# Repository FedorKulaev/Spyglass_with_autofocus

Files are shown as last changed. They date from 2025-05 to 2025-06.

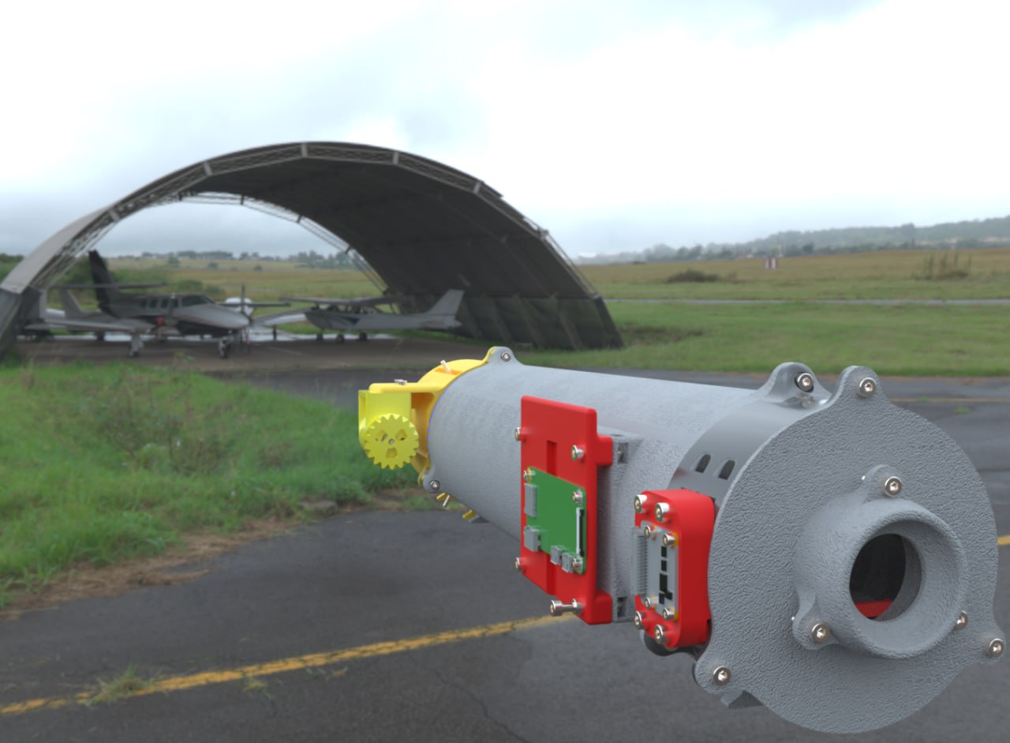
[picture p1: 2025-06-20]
Photo/photo_2025-06-21 00.15.42.jpeg

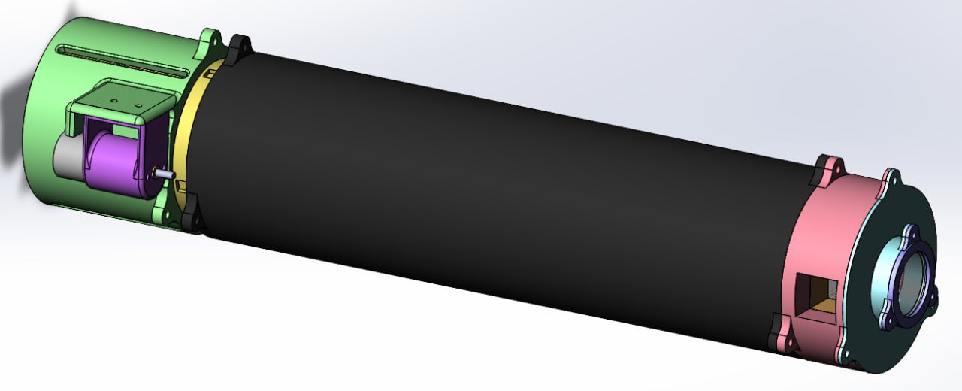
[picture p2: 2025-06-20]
Photo/photo_2025-06-21 00.15.21.jpeg

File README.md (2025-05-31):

# Краткое описание
Устройство представляет собой крупногабаритную подзорную трубу, которая обладает возможностью фокусироваться на объекты, находящиеся в диапазоне расстояний 3-10000 метров. Увеличение нашей трубы составляет 5.33, при этом изображение получается перевёрнутым. Для фокусировки устройству требуется порядка пары секунд, в течение которых подзорную трубу необходимо статично удерживать для корректной работы автофокуса.

# Команда
Кулаев Фёдор, группа Б04-303 

Ветров Алексей, группа Б04-303

# Цель проекта
Все сталкивались с проблемой, что при использовании бинокля при перенаведении его на более или менее удалённый предмет приходится двигать колёсико регулировки. Мы поставили перед собой задачу собрать устройство, которое сможет перефокусироваться автоматически. 

# Подробное описание устройства
Оптическая схема состоит из схемы Кеплера, где объектив - линза на 3 дптр, окуляр - линза на 16 дптр(Теоретическое увеличение такой схемы 5.33). В конце схемы мы добавили делитель луча. Одна половина луча попадает на камеру, с помощью которой мы понимаем, в фокусе находятся объекты или нет. Моторчиком двигаем одну линзу относительно другой до того момента, пока изображение не окажется сфокусированным. Моторчиком и состоянием фокусировки управляет микрокомпьютер. Питание за счёт powerbank.

# Компоненты
Объектив - линза для очков на 3 дптр (https://market.yandex.ru/product--linza-dlia-ochkov-sfericheskaia-1sht-ice-maker-d-65-index-1-70/1884922652?sku=102071359570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)

Окуляр - линза для очков на 16 дптр (https://market.yandex.ru/product--linza-dlia-ochkov-sfericheskaia-1sht-ice-maker-d-60-index-1-70/1884926108?sku=102071359528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)

Мотор DC205 RPM 

Драйвер к мотору TB6612FNG

Камера Pi-camera module 3

Микрокомпьютер Raspberry Pi 4 model B (изначально планировалась Raspberry Pi Zero v1.3)

PD-триггер для получения нужного напряжения с powerbank (https://www.ozon.ru/product/trigger-modul-fastcharge-9v-12v-15v-20v-1156203022/?reviewsVariantMode=2)

powerbank

# Трудности 
Наше устройство получилось довольно большим ввиду того, что мы не имеем возможности обрезать под нужный диаметр линзы, и поэтому в процессе разработки было принято решение вместо бинокля сделать подзорную трубу.

Мы хотели всё запитать с помощью одного powerbank, поэтому нам пришлось дополнительно приобрести PD-триггер для получения нужного напряжения на моторах

# Существующие аналоги
<([https://www.amazon.com/s?k=autofocus+binoculars)](https://www.amazon.com/Bushnell-Waterproof-Spectator-Binocular-10x50mm/dp/B07353SGQG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)>

<<https://binokl.shop/product/free-focus-bpsh-8x40>>

# Фото


# Видео

https://github.com/user-attachments/assets/4ccdcfca-6943-4ccf-b469-e8c1348ee5a3

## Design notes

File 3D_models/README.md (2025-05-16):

# Здесь представлены финальные версии 3D моделей всех распечатанных нами деталей
### Файлы .stl - оправы для линз, которые использовались в процессе тестирования оптической схемы
### Файл ПД-01 - сборка 3D моделей всех компонентов подзорной трубы

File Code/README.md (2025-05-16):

Тут лежат все версии программного кода, использованного нами в процессе создания и тестирования продукта

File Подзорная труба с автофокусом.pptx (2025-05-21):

## Подзорная труба с автофокусом

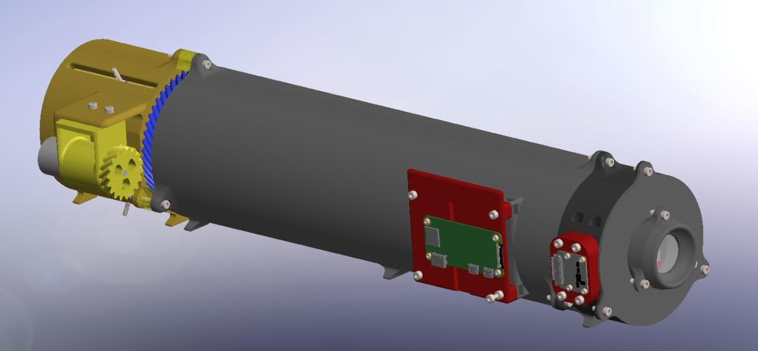
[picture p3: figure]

Команда:
Кулаев Фёдор Б04-303
Ветров Алексей Б04- 303

## Этапы создания

1. Тестирование оптической схемы
2. Проектирование компонентов
3. Печать и сборка
4. Работа с Raspberry PI
5. Подключение всех компонентов и отладка

## Тестирование оптической схемы

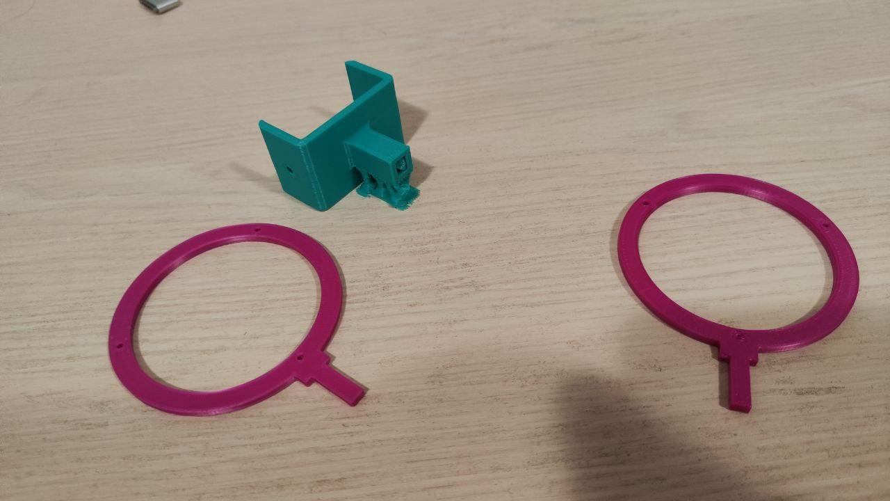
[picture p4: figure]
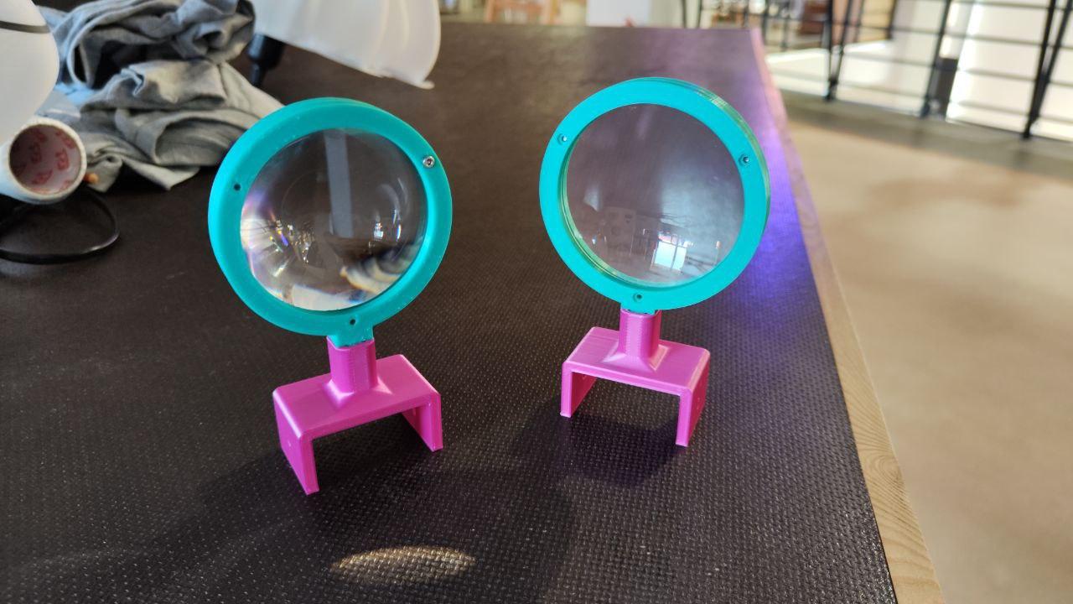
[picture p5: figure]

## Тестирование оптической схемы

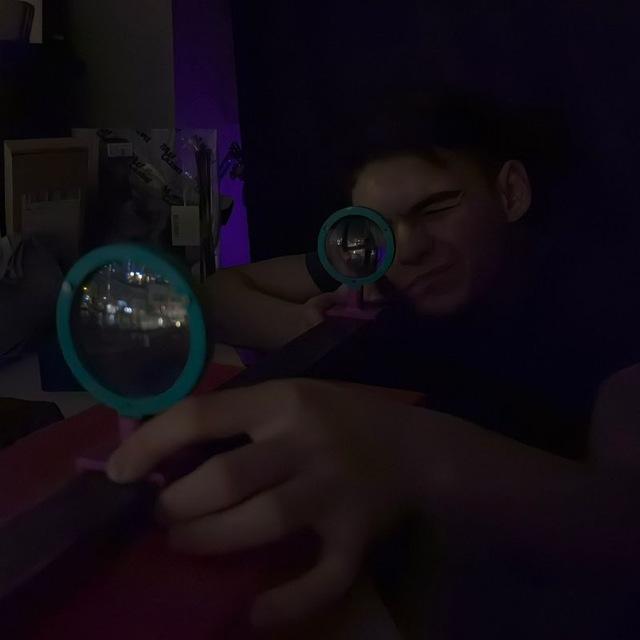
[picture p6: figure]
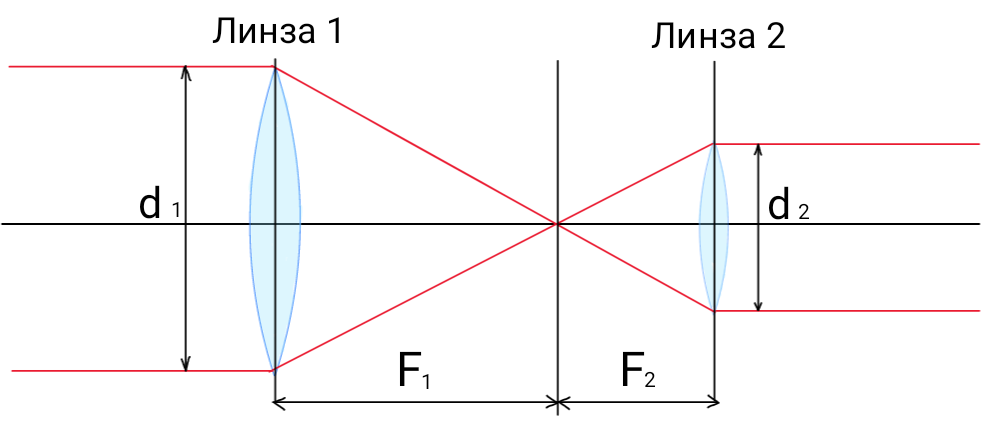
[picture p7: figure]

## 2. Проектирование компонентов

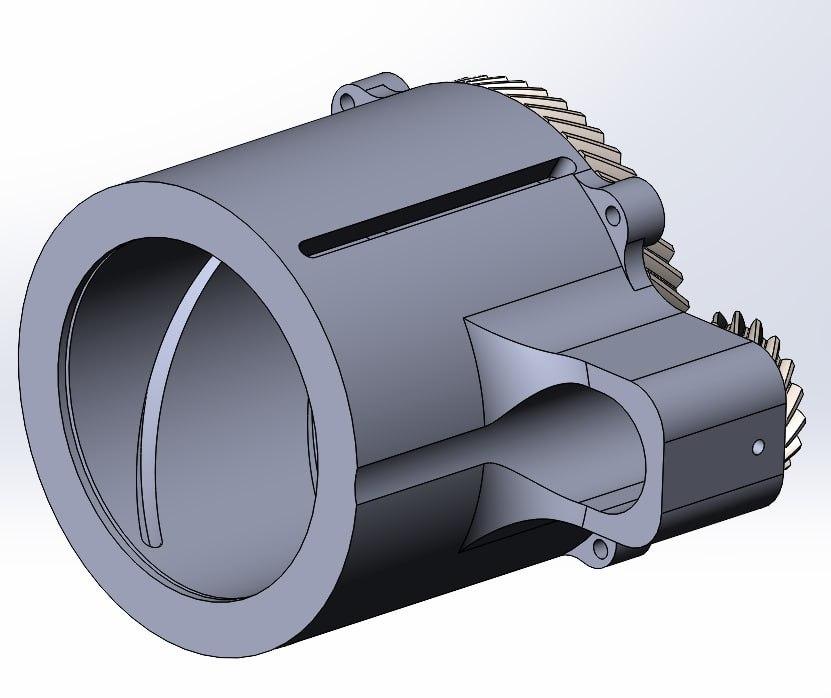
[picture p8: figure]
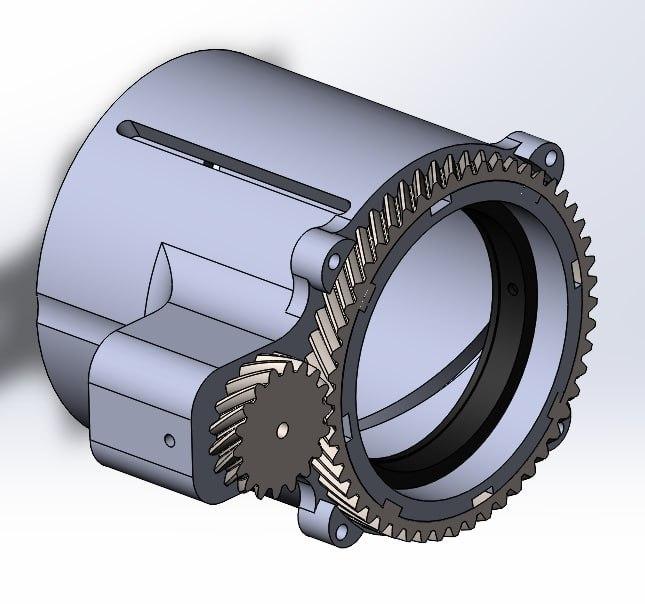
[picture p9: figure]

## 2. Проектирование компонентов

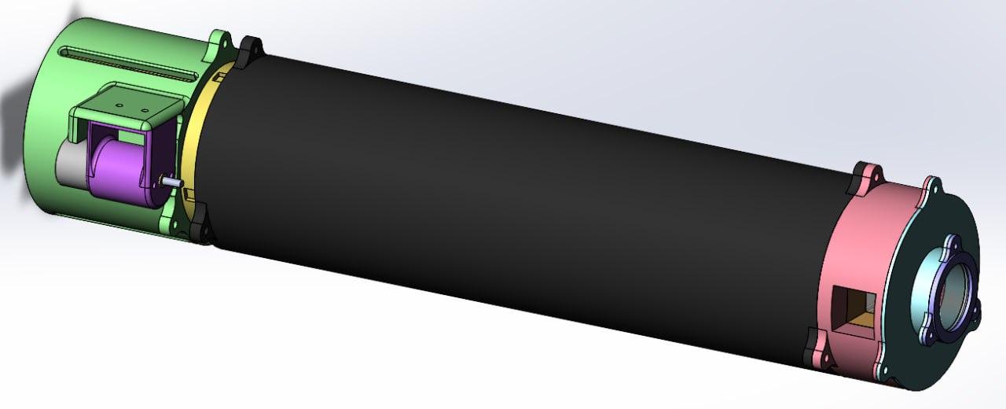
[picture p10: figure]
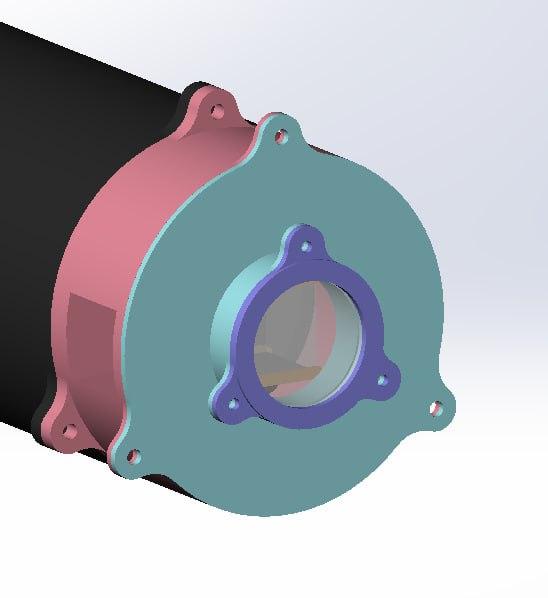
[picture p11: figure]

## 2. Проектирование компонентов

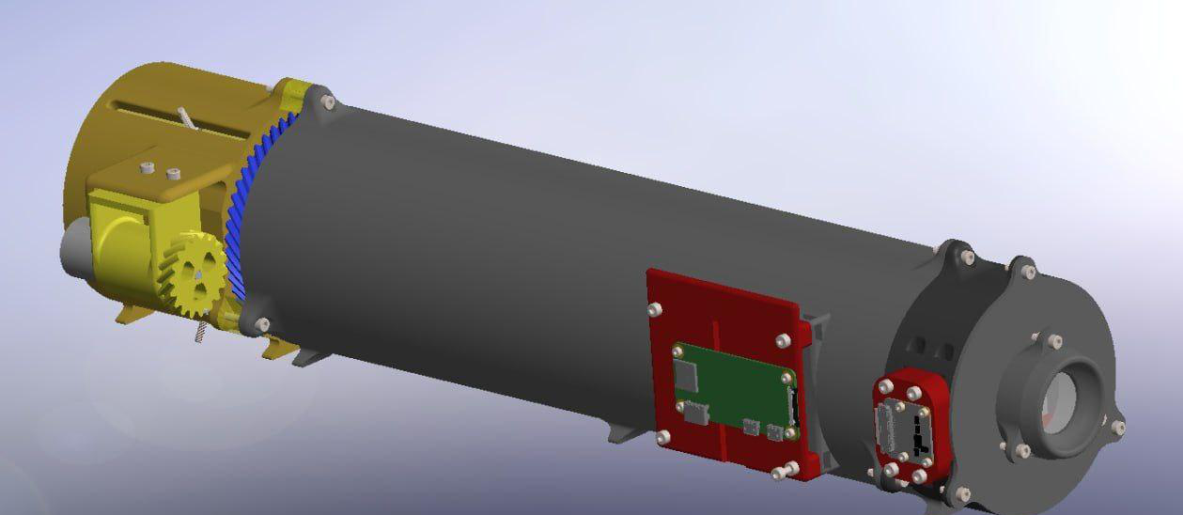
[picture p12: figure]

## 2. Проектирование компонентов

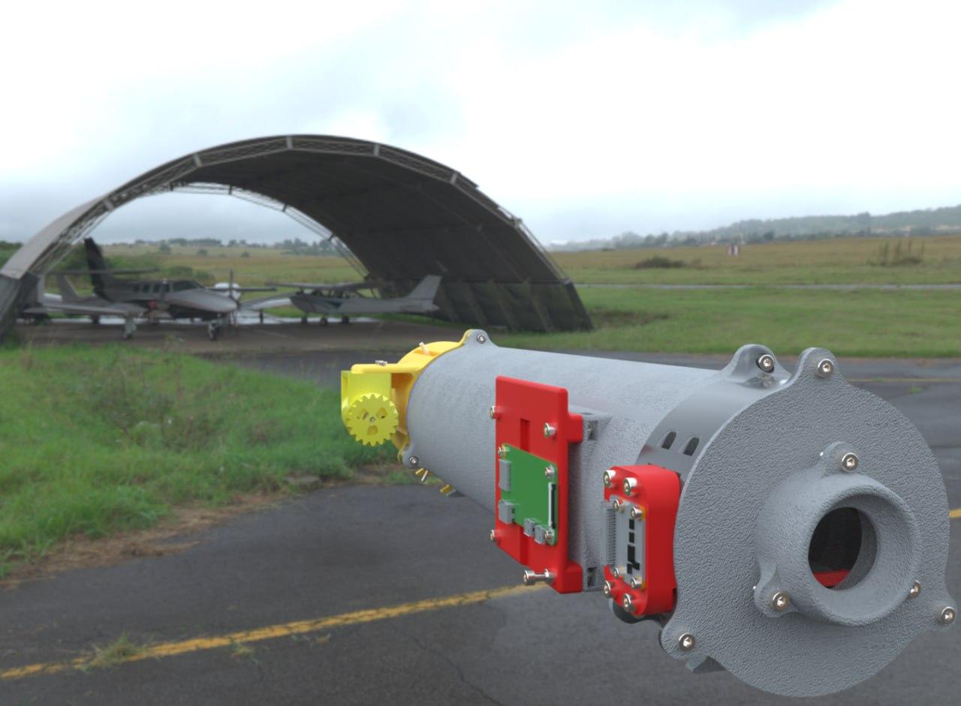
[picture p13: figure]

## 3. Печать и сборка

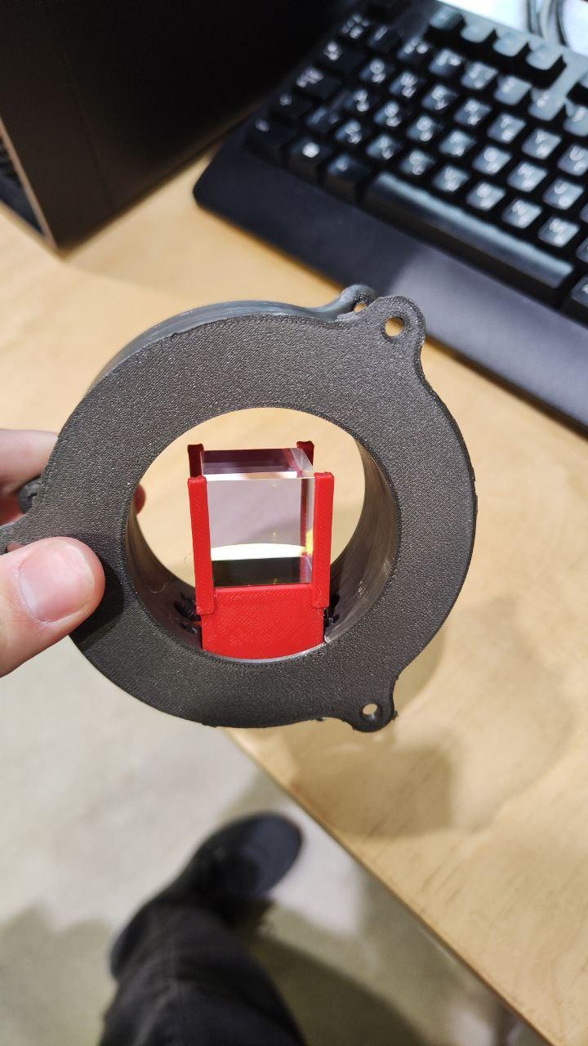
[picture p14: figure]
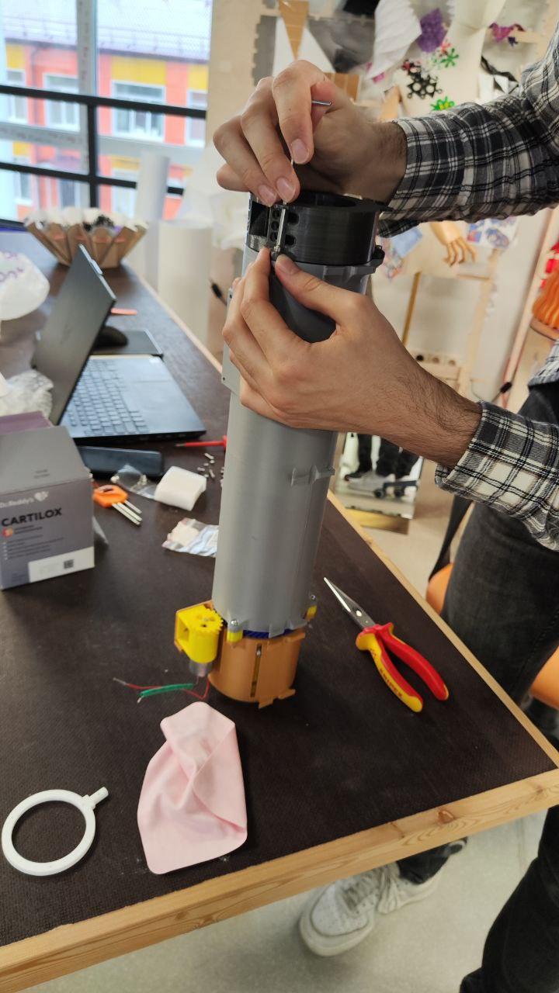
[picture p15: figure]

## 4. Работа с Raspberry Pi

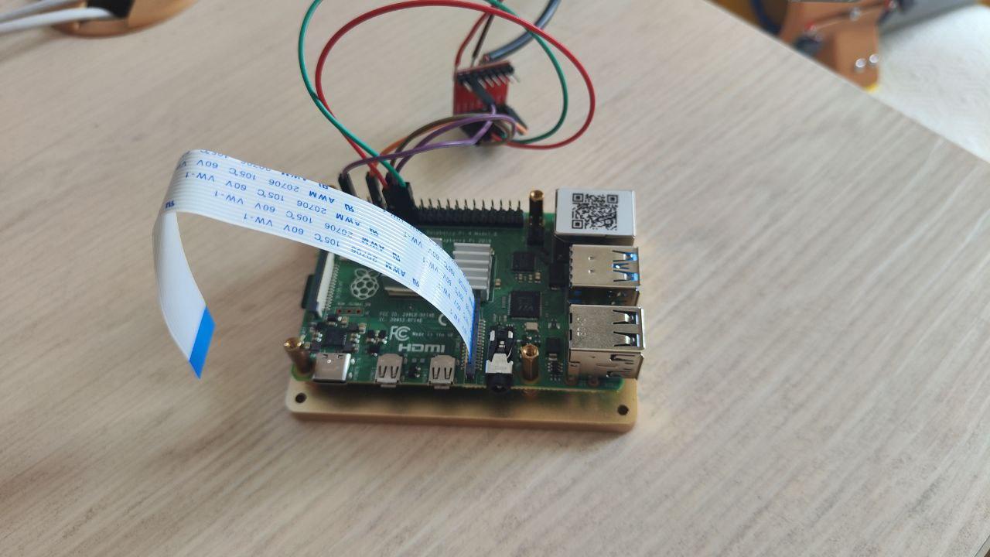
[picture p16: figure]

## 5. Подключение всех компонентов

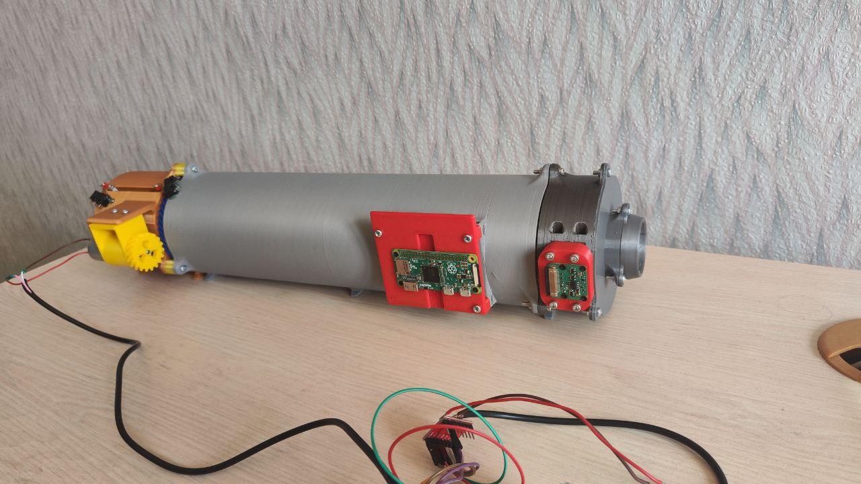
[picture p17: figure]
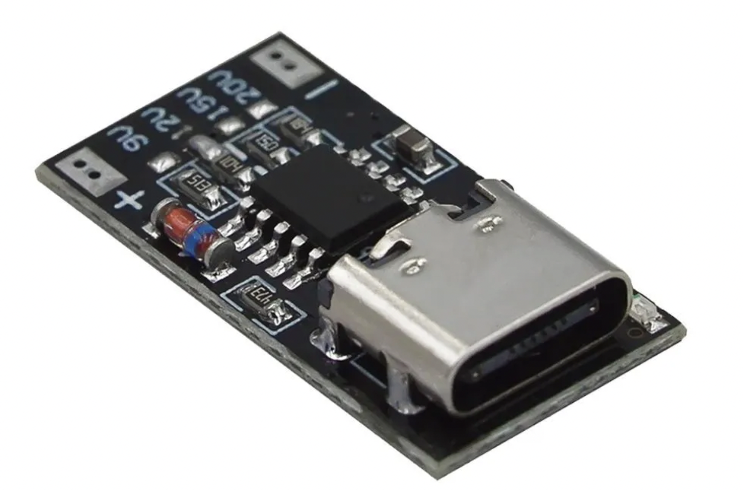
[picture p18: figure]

## Наш GitHub

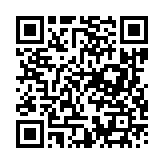
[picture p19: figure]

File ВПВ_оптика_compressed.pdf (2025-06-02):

# Общая физика: Оптика

# Вопрос по выбору

### Кулаев Фёдор Б04-303, Ветров Алексей Б04-303

2 июня 2025 г.

## 1 Цель работы:

- Исследовать и протестировать различные варианты оптических схем подзорных труб
- Спроектировать и собрать позорную трубу с автофокусировкой
- Сравнить реальное угловое увеличение устройства с теоретическим
- Пронаблюдать различные типы аббераций

## 2 Использованные материалы и оборудование:

Линзы: Собирающие +3D, +15D, +16D, +20D; Рассеивающая -20D. В итоговом устройстве установлены: окуляр - +16D и объектив - +3D.

Профиль металлический(1 метр); 3D-принтеры; метизы; камера RPi Camera Module 3; микрокомпьютер Raspberry Pi 4; делитель луча; мотор постоянного тока;

## 3 Выбор подходящей оптической схемы

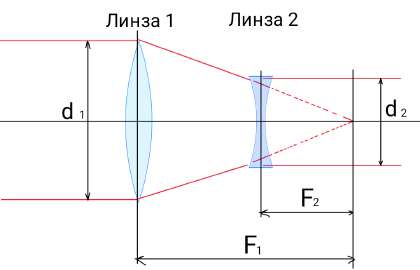
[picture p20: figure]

Схема Галиллея

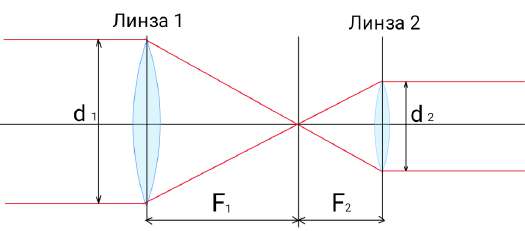
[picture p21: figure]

Схема Кеплера

1

Для обеих оптических схем увеличене вычисляется по формуле:

Г =

Dокуляра

Dобъектива

≈ 5.3

Мы распечатали оправы для линз и протестировали обе схемы на самодельной оптической скамье, представляющей из себя металлический профиль.

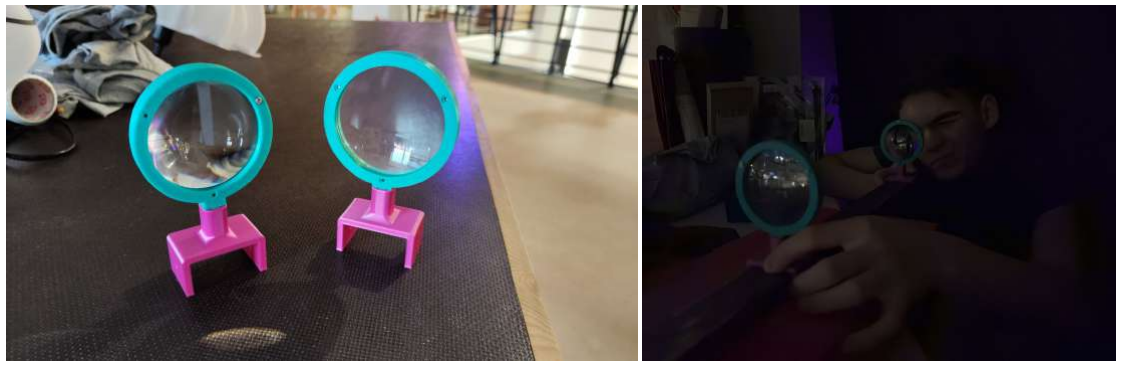
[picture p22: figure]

Оправы для линз | Тестирование

В качестве демонстрации мы сделали фотографии полученные с помощью телескопа по схеме Кеплера, используя три линзы - объектива на 3 диоптрии и окуляра - две сложенные вплотную линзы на 15 и 16 диоптрий. Теоретическое увеличение составляет чуть больше 10.

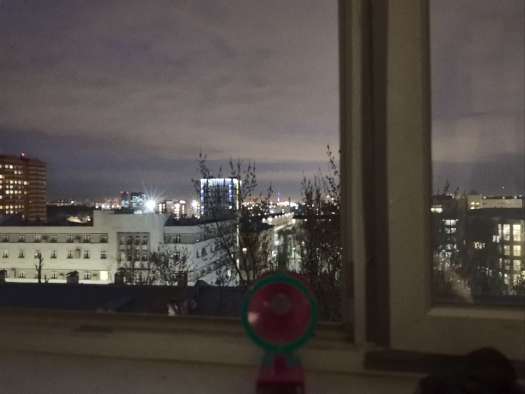
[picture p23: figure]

Без телескопа

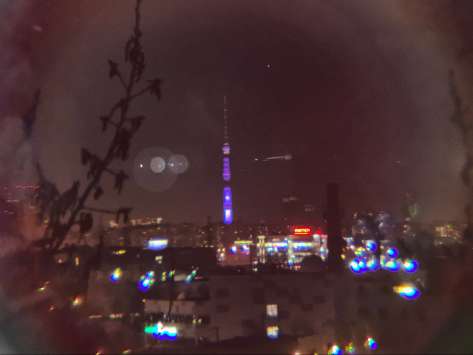
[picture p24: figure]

С телескопом (дополнительно перевернуто)

В итоге мы остановились на схеме Кеплера, в котором окуляр - собирающая линза на 16 диоптрий, а объектив - собирающая линза на 3 диоптрии. Для схемы Галиллея при наблюдении в рассеивающую линзу - собирающая линза с наблюдаемым объектом кажутся далеко, что усложнило бы работу автофокуса. Третью линзу в схему мы не стали ставить ввиду большого количества аберраций, которые искажали изображение и затрудняли работу автофокуса.

2

## 4 Сборка устройства

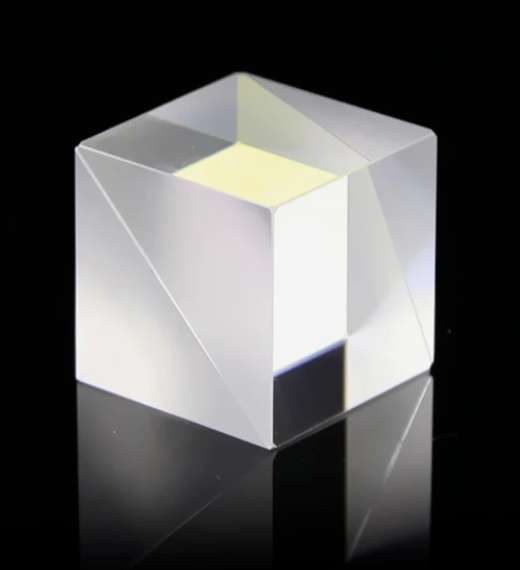
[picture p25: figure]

Делитель луча

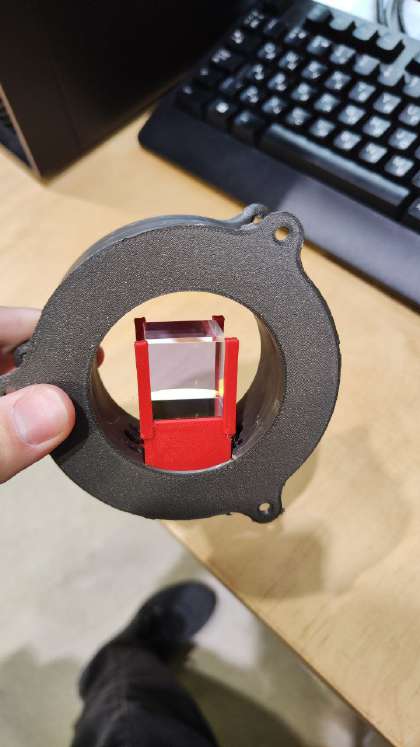
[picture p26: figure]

Делитель луча в сборке

3


Рис. 1 — Механизм движения объектива

Рис. 2 — Взрыв-схема всего устройства

4

## 5 Реализация контрастного автофокуса

1. Свет, прошедший через оптическую схему, попадает на делитель луча и раздваивается. Одна половина света попадает в глаз наблюдателя, а вторая - на камеру.
2. Далее выбираем зону, по которой будем вычислять значение функции контрастности -таким образом мы ограничиваем область, которая будет учитываться при анализе. При необходимости она может быть выбрана из любой части кадра, но для простоты будем вырезать центральную часть. Этот шаг подразумевает, что во время работы внутри области будут лежать точки на равном расстоянии до объектива.
3. Для каждого RGB пикселя с обрезанного изображения мы считаем воспринимаемую яркость по следующей формуле:

I = 0.299 ∗ R + 0.587 ∗ G + 0.114 ∗ B

Формула носит экспериментальный характер и показывает например, что зелёный цвет мы видим лучше всего, так как максимум чувствительности глаза при дневном освещении приходится на длину волны 560 нм.
Соответственно на этом этапе мы получили матрицу ’яркостей’
4. Далее для каждой пары соседних элеметов матрицы мы вычисляем модуль их разницы (тем самым получая градиент нашей дискретной функции двух переменных) и полученные значения складываем.
5. Итоговая сумма и будет значением функции контрастности при некотором положении линз.
6. Мы проходим весь диапазон движения линзы с малым шагом и находим положение, где функция контрастности максимальна.
7. Возвращаем линзу в это положение.

5

## 6 Экспериметальное измерение увеличения


Рис. 3 — Оптическая схема телескопа

В предположении что все углы малые, отношение угловых размеров предмета будет равняться просто отношению количества пикселей на фотографии, которые будет занимать наш предмет.

Г =

β
α

=

Lс телескопом

Lбез телескопа

=

N(пикселей)с телескопом

N(пикселей)без телескопа

6


Без телескопа | С телескопом

В этой паре изображений высота дома соответствовала 3470 пикселям с телескопом и 668 пикселям без телескопа.

7


Без телескопа | С телескопом

В следующей паре изображений высота останкинской башни соответствовала 3190 пикселям с телескопом и 610 пикселям без телескопа.
Мы провели ещё несколько измерений и итоговые результаты занесли в таблицу:
№эксперимента | N(пикселей)с телескопом | N(пикселей)без телескопа | Г
1 | 3470 | 668 | 5.2
2 | 3190 | 610 | 5.2
3 | 3510 | 662 | 5.3
4 | 2980 | 562 | 5.3
5 | 3240 | 626 | 5.2

Усредняя, получаем, что Гэкспериментальное = 5.2, при том, что теоретическое состовляет Гтеоретическое = 5.3.

8

## 7 Зависимость положения изображения от положения линз и расстояния до объекта

Для анализа возможных положений наблюдаемого изображения проведем расчеты в приближении тонкой линзы.


Рис. 4 — Схема формирования изображения

где a - расстояние между линзами, x1 - расстояние от объектива до даваемого им действительного изображения, L1 - расстояние от объекта до объектива, b - расстояние от окуляра до мнимого изображения. Нам интересна b, так как она с точностью до константы (расстояния от глаза до окуляра) будет описывать расстояние от глаза до изображения, которое мы будем наблюдать.

Запишем выражения:

x1 =

f1L1

L1 − f1
И далее, учитывая что расстояние от окуляра до действительного изображения - x2 = a − x1 получаем:

b =

(a − x1)f2

f2 − (a − x1)

Также приведем окончательную зависимость b(a, L1):

b =

(a −

f1L1
L1−f1

)f2
f2 − (a −

f1L1
L1−f1

)

Для анализа построим поверхность, которую задает это уравнение, в координатах (x; y; z)=(L1; a; b). Также построим сечения полученной поверхности плоскостями L1 = const с шагом 10м и
a = const с шагом 1мм.

9


Рис. 5 — Зависимость расстояния до видимого изображения

Сечения a = const | Сечения L1 = const

10

## 8 Описание готового устройства

Устройство представляет собой крупногабаритную подзорную трубу, которая обладает возможностью фокусироваться на объекты, находящиеся в диапазоне расстояний 3-10000 метров. Увеличение нашей трубы составляет 5.33, при этом изображение получается перевёрнутым. Для фокусировки устройству требуется порядка пары секунд, в течение которых подзорную трубу необходимо статично удерживать для корректной работы автофокуса.

## 9 Различные способы релизации автофокуса

В различных оптических приборах и фототехнике существует три основных типа автофокуса:

- Контрастный
В профессиональных камерах алгоритм схож с нашим. Основное отличие в высокой точности и скорости обработки входных данных, что позволяет релизовывать фокусировку методом градиентного спуска (максимизируя функцию контрастности). Это, в свою очередь, дает возможность использовать автофокус в ”следящем” режиме.
- Фазовый
В этом варианте входной пучок света делится на две части. Основная попадает на матрицу, а остальная на специальное устройство, схема которого представлена на рисунке:


Рис. 6 — Схема фазового автофокуса

Соответственно, датчик измеряет расстояние между пятнами от от двух разделённых пучков света. После обработки полученных данных механизм смещает линзу.

Данный автофокус имеет несколько преимуществ по сравнению с контрастным: по расстоянию между пятнами мы сразу можем понять, на какое расстояние и в какую сторону

11 необходимо сдвинуть линзу, что заметно ускоряет процесс, а также он более эффективен в условиях низкой освещенности.

- Лазерный
В этом случае дополнительно устанавливается лазерный дальномер, который определяет абсолютное расстояние об объекта до объектива. Из полученного значения рассчитывается оптимальное положение линз. Этот способ является одним из самых точных и быстрых, так как лазер позволяет очень точно измерить расстояние, также он абсолютно не зависит от условий освещения. Но у него есть и существенный минус: с ростом расстояния до объекта сильно возрастает необходимая мощность лазера, что ограничивает область применения.

(можно привести численное значение по формулам рассеяния Рэелеевского и поглощения по Бугеру-Ламберту-Беру)

## 10 Аберрации

Различные абберации (искажения) являются неотъемлемой частью любого оптического прибора, в том числе и нашей подзорной трубы. Продемонстрируем различные виды аббераций и пронаблюдаем их на примере собранного устройства.

### 10.1 Хроматические аберрации

На практике линзы не идеальны и для материала, из которого они изготовлены есть дисперсия. Соответственно, оптическая плотность для каждого из цветов разная, из-за чего фокусное растояние линзы для разных длин волн своя.


Рис. 7 — Хроматические аберрации

Количественно дисперсионные свойства материалов и соответственно то, насколько сильно

12 будут наблюдаться хроматические аберрации при изготовлении стекла из соответствующего материала, описывает число Аббе Vd.

Vd =

nd − 1
nF − nC

где:

- nd – показатель преломления для жёлтой линии гелия d (587.6 нм)
- nF – показатель преломления для синей линии водорода F (486.1 нм)
- nC – показатель преломления для красной линии водорода C (656.3 нм)

Чем выше Vd, тем меньше материал подвержен хроматическим аберрациям.

Существуют способы ахроматизации системы линз. Ниже приведем одну из них:

Запишем изменение фокусного расстояния линзы δf в зависимости от изменения показателя преломления δn:
f
δf = −

n − 1
δn
Примем, что δn = nC − nf , n ≈ nD, тогда формула преобразуется в f δf = Vd. Также с учетом
формулы для фокусного расстояния системы линз 1
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
f1f2

получим условие на
ахроматизацию (δf = 0):
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
f1f2
δf1
f1

+

δf2
f2
= 0

Которое при подстановке полученных выше равенств обретает удобный вид:

f2

Vd1

+

f1

Vd2

= l(

1

Vd1

+

1

Vd2

)

13

### 10.2 Сферические абберации

Из-за отличия сферической поверхности от параболической и гиперболической при работе с непараксиальными лучами мы наблюдаем сферические абберации.

Рис. 8 — Сферическая аберрация простой линзы

Сферическую аберрацию удается устранить лишь для определенного расстояния до предмета. Для зрительных труб и обычных фотообъективов выбирают удаленный предмет, объективы микроскопов коррегируют для положения предмета непосредственно перед фокусом

Остальные типы аббераций возникают, если объект лежит не на оптической оси системы.

### 10.3 Кома

Эта аберрация возникает при отображении внеосевых точек предмета широкими пучками лучей. Лучи из точки Q, проходящие ближе к краям линзы, преломляются сильнее, чем требуется для их схождения в точку Q’ пересечения параксиальных лучей, и образуют в плоскости параксиальных изображений кружки рассеяния, которые заполняют область между прямыми, выходящими из Q’.


Рис. 9 — Абберация комы

### 10.4 Дисторсия

В оптических системах возможно искажение геометрической формы изображения протяженного предмета. Если линейное увеличение растет по мере удаления от оптической оси к краям

14 поля зрения, изображение квадрата приобретает вид «подушки» (а) Так бывает при расположении ограничивающей пучки диафрагмы позади линзы.


Рис. 10 — Дисторсия при разных положениях диафрагмы

Если диафрагма находится перед линзой, увеличение по краям поля зрения меньше, чем в центре, и изображение квадрата приобретает вид «бочки» (б). В системе двух линз при расположении диафрагмы между линзами можно добиться почти полного уничтожения дисторсии, так как подушкообразная дисторсия, создаваемая первой линзой, компенсируется бочкообразной дисторсией второй линзы.

15

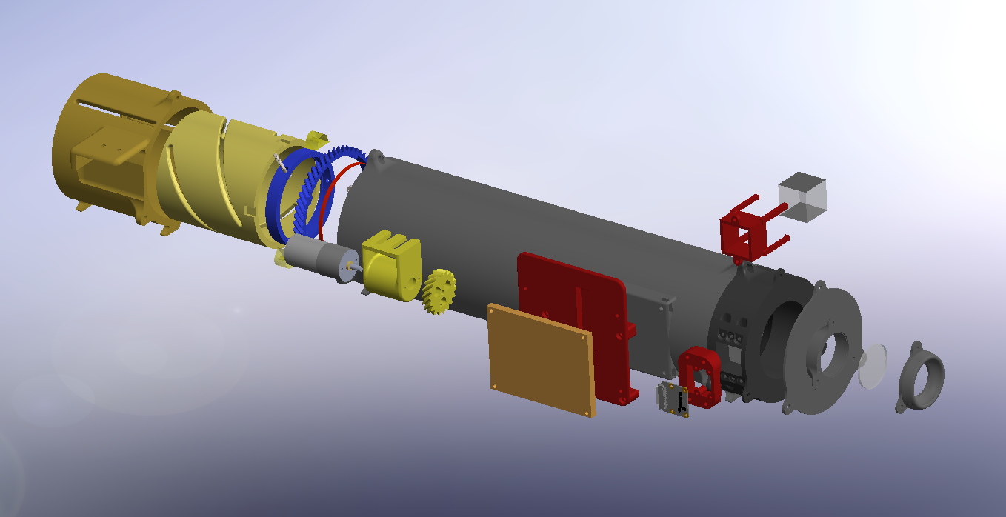
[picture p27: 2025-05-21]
Photo/Взрыв-фото.png

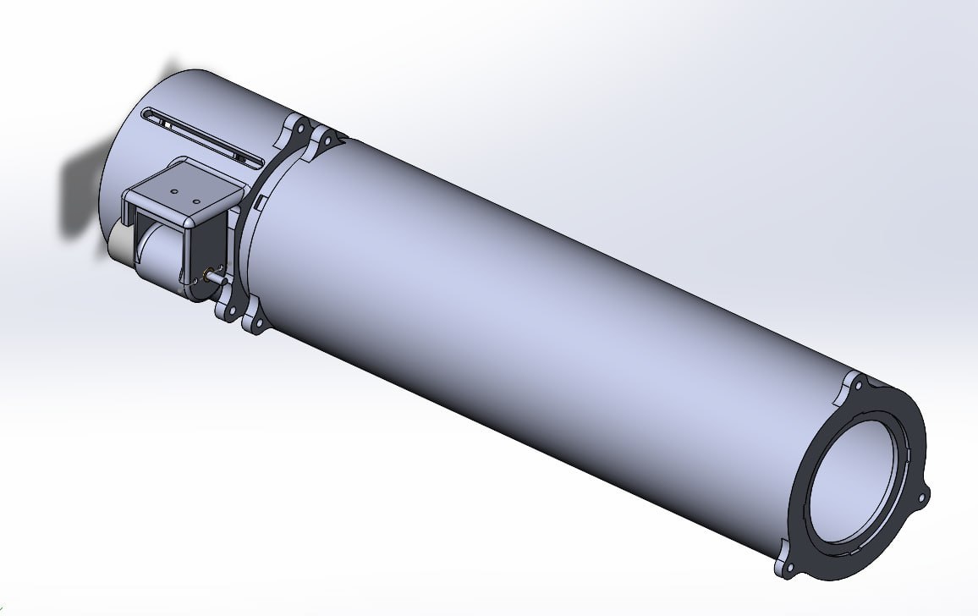
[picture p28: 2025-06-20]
Photo/photo_2025-06-21 00.15.15.jpeg

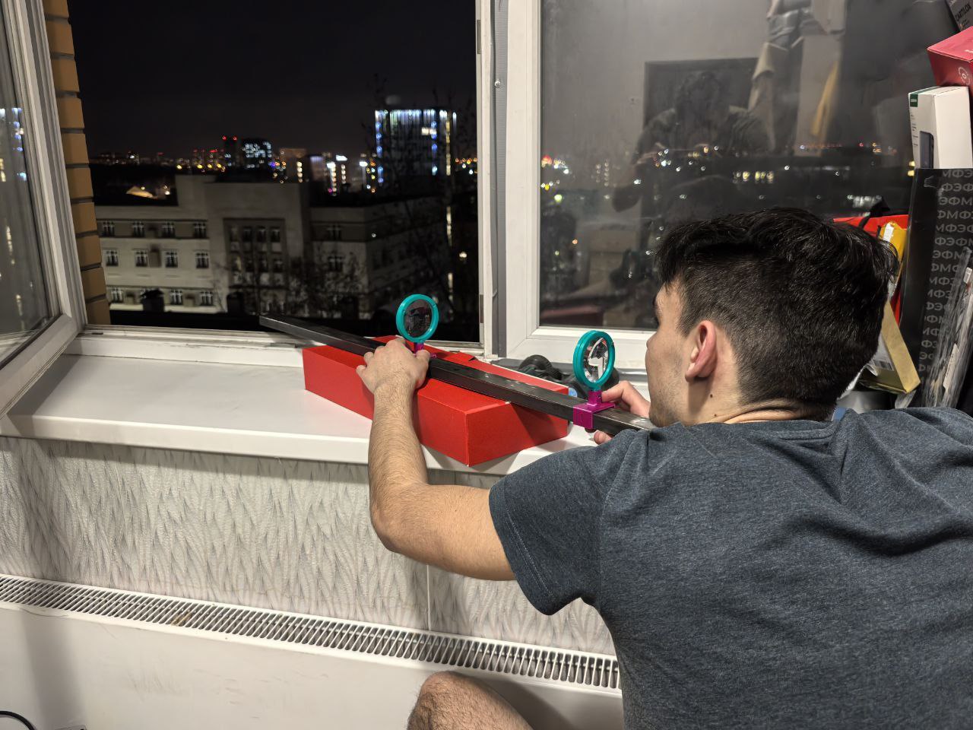
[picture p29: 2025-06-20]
Photo/photo_2025-06-21 00.14.57.jpeg

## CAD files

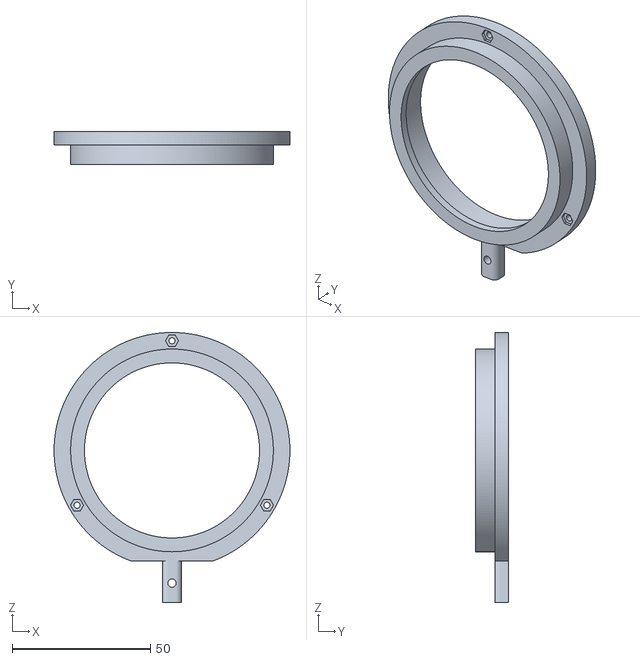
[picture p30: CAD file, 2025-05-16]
3D_models/Lens_mount_4.STL
85.3 x 12.0 x 97.6

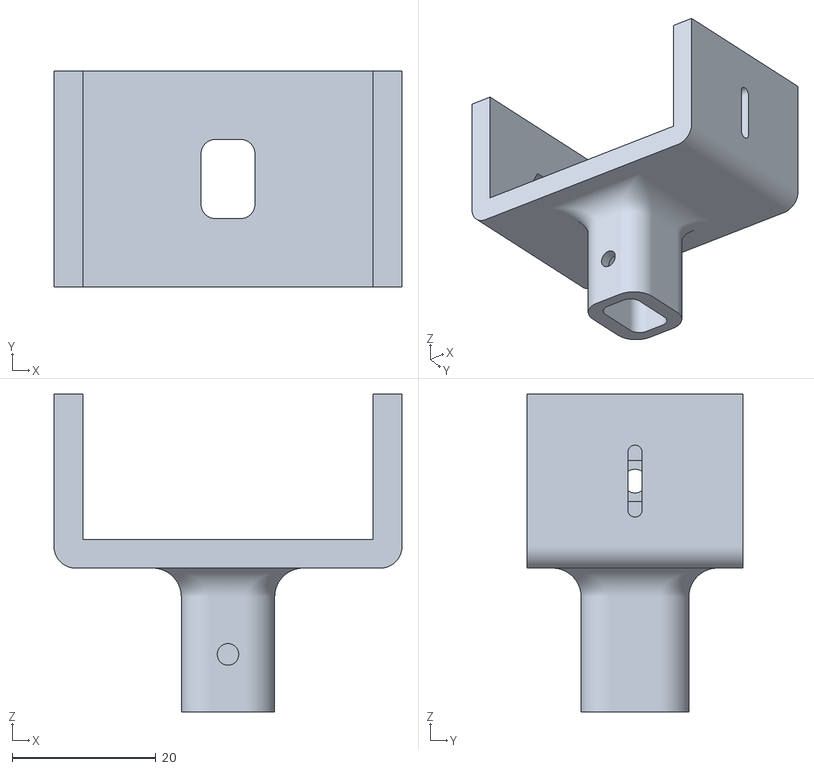
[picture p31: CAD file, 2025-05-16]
3D_models/Mount_base_v1.STL
48.4 x 30.0 x 44.2

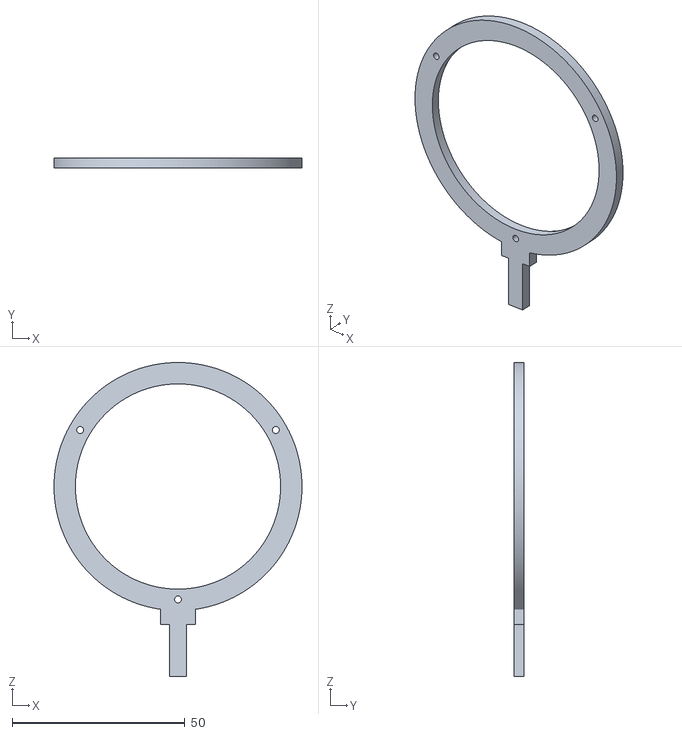
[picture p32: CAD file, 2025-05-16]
3D_models/Маунт на линзу D15 - ответная часть.STL
71.8 x 3.00 x 90.9

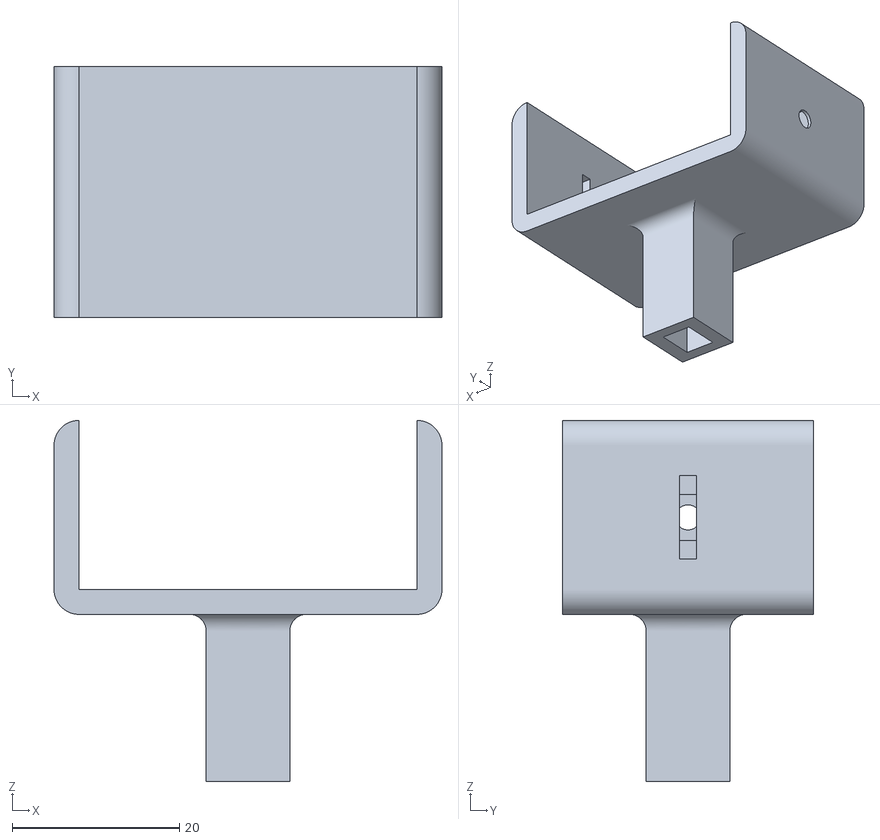
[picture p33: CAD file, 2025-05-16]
3D_models/Штатив_основание.STL
46.4 x 30.0 x 43.2

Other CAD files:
3D_models/Lens_mount_4_sec_part.STL
3D_models/Маунт на линзу D15.STL

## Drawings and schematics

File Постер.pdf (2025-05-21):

# П О ДЗ О Р Н А Я Т Р У Б А С АВТ О Ф О К У С О М

## К О М А Н Д А

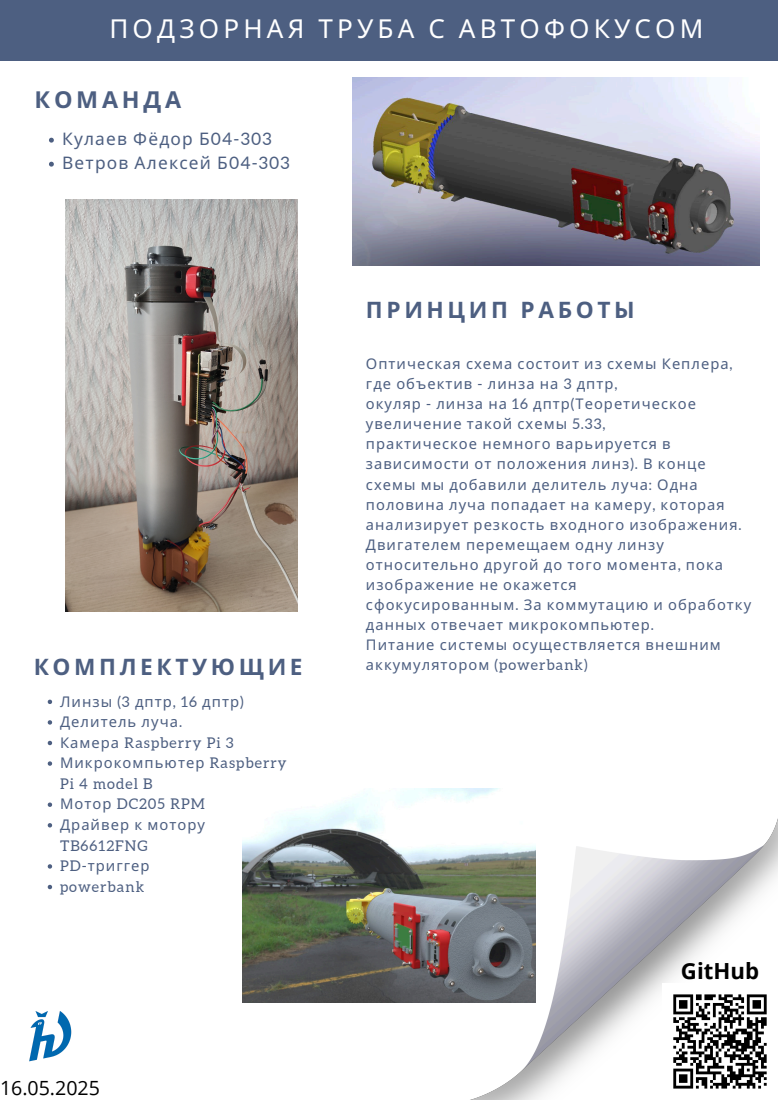
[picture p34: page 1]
П Р И Н Ц И П РАБ О Т Ы; Кулаев Фёдор Б04-303 Ветров Алексей Б04-303; К О М П Л ЕКТУЮЩИ Е; GitHub

Оптическая схема состоит из схемы Кеплера,
где объектив - линза на 3 дптр,
окуляр - линза на 16 дптр(Теоретическое
увеличение такой схемы 5.33,
практическое немного варьируется в
зависимости от положения линз). В конце
схемы мы добавили делитель луча: Одна
половина луча попадает на камеру, которая
анализирует резкость входного изображения.
Двигателем перемещаем одну линзу
относительно другой до того момента, пока
изображение не окажется
сфокусированным. За коммутацию и обработку
данных отвечает микрокомпьютер.
Питание системы осуществляется внешним
аккумулятором (powerbank)

Линзы (3 дптр, 16 дптр)
Делитель луча.
Камера Raspberry Pi 3
Микрокомпьютер Raspberry
Pi 4 model B
Мотор DC205 RPM
Драйвер к мотору
TB6612FNG
PD-триггер
powerbank

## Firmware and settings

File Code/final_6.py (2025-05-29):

import pigpio
import time
from picamera2 import Picamera2, Preview
import numpy as np

# Пины GPIO
AIN1 = 17   # IN1 (направление)
AIN2 = 27   # IN2 (направление)
PWMA = 18   # PWM (скорость)
STBY = 22   # STBY (включение драйвера)
conc = 4
button = 10      #Прописать номер пина

pi = pigpio.pi()

# Настройка пинов
pi.set_mode(AIN1, pigpio.OUTPUT)
pi.set_mode(AIN2, pigpio.OUTPUT)
pi.set_mode(STBY, pigpio.OUTPUT)
pi.set_mode(PWMA, pigpio.OUTPUT)
pi.set_mode(conc, pigpio.INPUT)
pi.set_pull_up_down(conc, pigpio.PUD_DOWN)
pi.set_mode(button, pigpio.INPUT)
pi.set_pull_up_down(button, pigpio.PUD_DOWN)
# Включить драйвер
pi.write(STBY, 1)


def motor_control(speed, direction):
    if direction == 1:
        pi.write(AIN1, 1)
        pi.write(AIN2, 0)
    elif direction == -1:
        pi.write(AIN1, 0)
        pi.write(AIN2, 1)
    elif direction == 0:
        pi.write(AIN1, 0)
        pi.write(AIN2, 0)
    pi.set_PWM_dutycycle(PWMA, speed)  # speed: 0-255
    

# Инициализация камеры
picam2 = Picamera2()

# Параметры области анализа (ROI)
roi_width, roi_height = 150, 150
roi_x, roi_y = 910, 520

# Конфигурация камеры
config = picam2.create_preview_configuration(
    main={"size": (1920, 1080), "format": "RGB888"},
    controls={"AfMode": 0, "LensPosition": 10}  # Ручной режим фокуса
)
picam2.configure(config)
picam2.start()

def calculate_fom(image_roi):
    # Конвертация в grayscale (формула NTSC)
    gray = image_roi[:,:,0] * 0.299 + image_roi[:,:,1] * 0.587 + image_roi[:,:,2] * 0.114
    
    # Расчет градиентов через numpy
    grad_x = np.abs(np.gradient(gray, axis=1))
    grad_y = np.abs(np.gradient(gray, axis=0))
    
    # FoM как сумма абсолютных значений градиентов
    return np.sum(grad_x + grad_y)


# Функция для вывода значения резкости
def rez():
    image = picam2.capture_array("main")
    roi = image[roi_y:roi_y+roi_height, roi_x:roi_x+roi_width]
    return calculate_fom(roi)

# Функция немного двигает линзу в направлении d и выводит новое значение резкости
def next_step(d):
    motor_control(70, d)
    time.sleep(0.03)
    motor_control(70, 0)
    time.sleep(0.02)
    return rez()

def turn_off():
    pi.write(AIN1, 0)
    pi.write(AIN2, 0)
  # Подобрал наиболее близкое к глазу



def pusk():
    # Двигаем в начало отсчёта
    arr = []
    if not pi.read(conc):  #Если замкнут
        cash = next_step(-1)
        cash = next_step(-1)
        if pi.read(conc): 
            motor_control(120, -1)
            while pi.read(conc):
                time.sleep(0.01)
            else:
                motor_control(70, 0)
    else:
        motor_control(120, -1)
        while pi.read(conc):
            time.sleep(0.01)
        else:
            motor_control(70, 0)
            
    arr.append(next_step(1))
    arr.append(next_step(1))
    arr.append(next_step(1))
    while pi.read(conc):
        arr.append(next_step(1))

    m = max(arr)
    for i in range(1, len(arr)+1):
        if (arr[-i] == m):
            break
        cash = next_step(-1)
    turn_off()

turn_off()
while True:
    time.sleep(0.05)
    if pi.read(button):
        pusk()
        time.sleep(1.4)

turn_off()
pi.write(STBY, 0)
pi.stop()
picam2.stop()

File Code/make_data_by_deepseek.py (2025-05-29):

import pigpio
import time
from picamera2 import Picamera2
import numpy as np
import matplotlib.pyplot as plt
from threading import Thread

# Настройки оборудования
GPIO_CONFIG = {
    "AIN1": 17,
    "AIN2": 27,
    "PWMA": 18,
    "STBY": 22,
    "CONC": 4
}

# Параметры системы
ROI_SIZE = (40, 40)  # Уменьшенная область интереса
ROI_POS = (910, 520)
MOTOR_SPEED = 70
SAMPLE_DELAY = 0.001  # 1 ms между измерениями

# Инициализация GPIO
pi = pigpio.pi()
for pin in [GPIO_CONFIG["AIN1"], GPIO_CONFIG["AIN2"], GPIO_CONFIG["PWMA"], GPIO_CONFIG["STBY"]]:
    pi.set_mode(pin, pigpio.OUTPUT)
pi.set_mode(GPIO_CONFIG["CONC"], pigpio.INPUT)
pi.set_pull_up_down(GPIO_CONFIG["CONC"], pigpio.PUD_DOWN)
pi.write(GPIO_CONFIG["STBY"], 1)

# Настройка ШИМ
pi.set_PWM_frequency(GPIO_CONFIG["PWMA"], 1000)
pi.set_PWM_range(GPIO_CONFIG["PWMA"], 255)

# Инициализация камеры с оптимизированными настройками
picam2 = Picamera2()
config = picam2.create_preview_configuration(
    main={"size": (ROI_SIZE[0]*2, ROI_SIZE[1]*2), "format": "RGB888"},
    controls={"AfMode": 0, "LensPosition": 10, "FrameRate": 60}
)
picam2.configure(config)
picam2.start()

# Глобальные переменные для многопоточности
data_queue = []
running = True
roi_slice = (slice(ROI_POS[1], ROI_POS[1]+ROI_SIZE[1]), 
             slice(ROI_POS[0], ROI_POS[0]+ROI_SIZE[0]))

def motor_control(speed, direction):
    """Оптимизированное управление мотором"""
    pi.write(GPIO_CONFIG["AIN1"], direction > 0)
    pi.write(GPIO_CONFIG["AIN2"], direction < 0)
    pi.set_PWM_dutycycle(GPIO_CONFIG["PWMA"], speed if direction else 0)

def calculate_fom(image):
    """Быстрый расчет показателя резкости по красному каналу"""
    return np.sum(np.abs(np.gradient(image[..., 0])))

def capture_thread():
    """Поток для непрерывного захвата данных"""
    global data_queue
    while running:
        try:
            image = picam2.capture_array("main")[roi_slice]
            data_queue.append(calculate_fom(image))
            time.sleep(SAMPLE_DELAY)
        except:
            break

def main():
    global running
    Thread(target=capture_thread, daemon=True).start()
    
    try:
        while pi.read(GPIO_CONFIG["CONC"]):
            # Цикл движения мотора
            motor_control(MOTOR_SPEED, 1)
            start_time = time.monotonic()
            
            # Сбор данных в течение 50 ms
            while time.monotonic() - start_time < 0.05:
                pass
                
            # Остановка и сбор оставшихся данных
            motor_control(0, 0)
            time.sleep(0.02)  # Краткая пауза
            array.extend(data_queue)
            data_queue.clear()
            
    finally:
        running = False
        motor_control(0, 0)
        pi.write(GPIO_CONFIG["STBY"], 0)
        pi.stop()
        picam2.stop()
        
        # Анализ и визуализация
        plt.figure(figsize=(12, 6))
        plt.plot(array, 'b-', linewidth=0.5)
        plt.title(f"Профиль резкости ({len(array)} измерений)")
        plt.grid(True)
        plt.show()
        
        print(f"Собрано точек: {len(array)}")
        print(f"Максимальное значение: {np.max(array)}")
        print(f"Средняя частота: {len(array)/(time.monotonic()-start_time):.1f} Hz")

if __name__ == "__main__":
    main()

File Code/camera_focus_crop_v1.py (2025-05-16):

from picamera2 import Picamera2
import time

picam2 = Picamera2()

# Настройка кропа (x, y, width, height) относительно полного разрешения
crop_width, crop_height = 1000, 800  # Желаемые размеры после кропа
crop_x, crop_y = 200, 150  # Смещение от левого верхнего угла

# Создаем конфигурацию с кропом
config = picam2.create_still_configuration(
    main={
        "size": (crop_width, crop_height),  # Размер выхода
        "format": "RGB888",
    },
    raw={
        "size": picam2.sensor_resolution,  # Полное разрешение сенсора
    },
    buffer_count=2,
    controls={
        "ScalerCrop": (crop_x, crop_y, crop_width, crop_height),  # Область кропа
    }
)

picam2.configure(config)
preview_config = picam2.create_preview_configuration()
picam2.start(show_preview=True)
time.sleep(20)
# Захватываем кадр (уже обрезанный)
image = picam2.capture_array("main")  # shape=(crop_height, crop_width, 3)
picam2.stop()

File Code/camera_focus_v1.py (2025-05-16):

# Подключаем необходимые библиотеки
from picamera2 import Picamera2, Preview
from time import sleep
from libcamera import controls
from pprint import pprint
 
 
def is_focused_waiting(cam_object):
    success = cam_object.autofocus_cycle()
    return success
    
    
def is_focused_async(cam_object):
    job = cam_object.autofocus_cycle(wait=False)
    success = cam_object.wait(job)
    return success    
    
# Создаём объект для работы с камерой
camera = Picamera2()  
# Настраиваем окно предпросмотра
preview_config = camera.create_preview_configuration()
camera.configure(preview_config)
 
# Запускаем окно предпросмотра сигнала с камеры на экране поверх всех окон
#camera.start_preview(Preview.QTGL)
 
# Включаем камеру
camera.start(show_preview=True)
#camera.set_controls({"AfMode": controls.AfModeEnum.Continuous})

focus = 5.0

for i in range(1, 10000):
    b = int(input())
    
    if (b == 3):
        focus += 0.1
    elif b == 1:
        focus -= 0.1
    elif b == 6:
        focus += 0.3
    elif b == 4:
        focus -= 0.3
    camera.set_controls({"LensPosition": focus})	
    #print("cycle", i, "; is_camera_focused: ", is_focused_async(camera), sep='')
    sleep(0.5)
    metadata = camera.capture_metadata()
    #print(metadata["FocusFoM"])# Проверяем, есть ли полезные данные (например, FocusFoM)
    print(metadata["LensPosition"], metadata["FocusFoM"])

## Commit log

2025-05-16 добавлена записка к проекту
2025-05-16 Rename ПД-01(Открывать Сборка_вращения).zip to ПД-01.zip
2025-05-21 Добавлен постер
2025-05-21 Взрыв - фото
2025-05-29 Add files via upload
    добавлены последние версии кодов
